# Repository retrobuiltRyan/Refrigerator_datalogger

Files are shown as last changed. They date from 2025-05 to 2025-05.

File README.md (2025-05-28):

What happens to your refrigerator temperature when you open the door? When you leave the door open? I built a data-logging device and stuck it in my fridge for a few hours to find out. I have no idea why I spent a weekend doing this.
Arduino logs temp and humidity data to a microSD card. Use exel to graph and plot data. A photosensor confirms the fridge light if you open the door. Sample graph of data is shown. The old fridge form this experience has a wide temp swing. Not a great fridge, ( came with the rental).

circuit

https://youtu.be/RkxqKmEyWRI

data spoiler

PCB (Arduino Uno shield) too! Note the i2c pwr lables have a text error on the silkscreen. (oops)
PCB

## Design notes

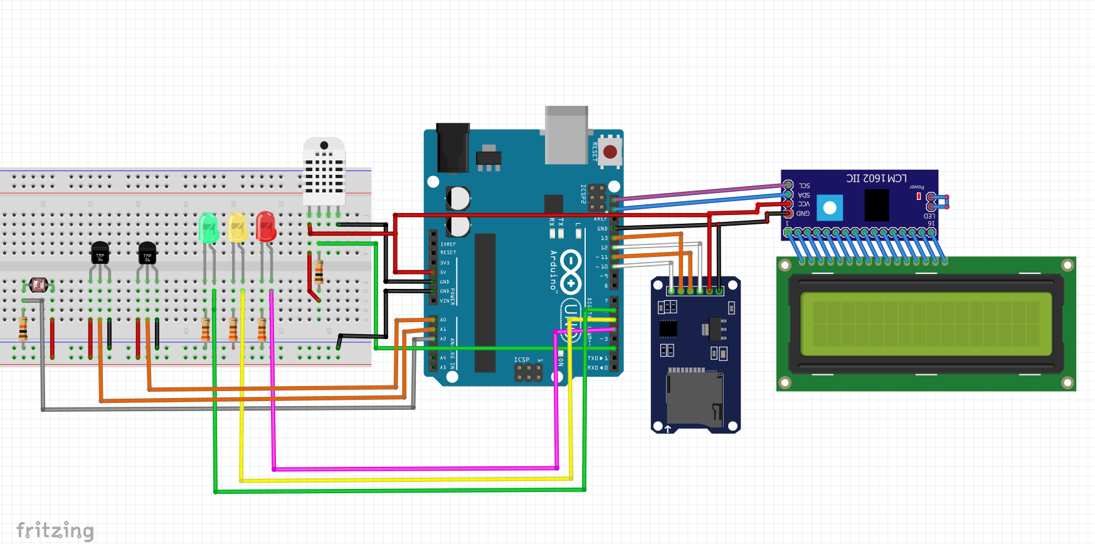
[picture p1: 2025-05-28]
circuit.PNG

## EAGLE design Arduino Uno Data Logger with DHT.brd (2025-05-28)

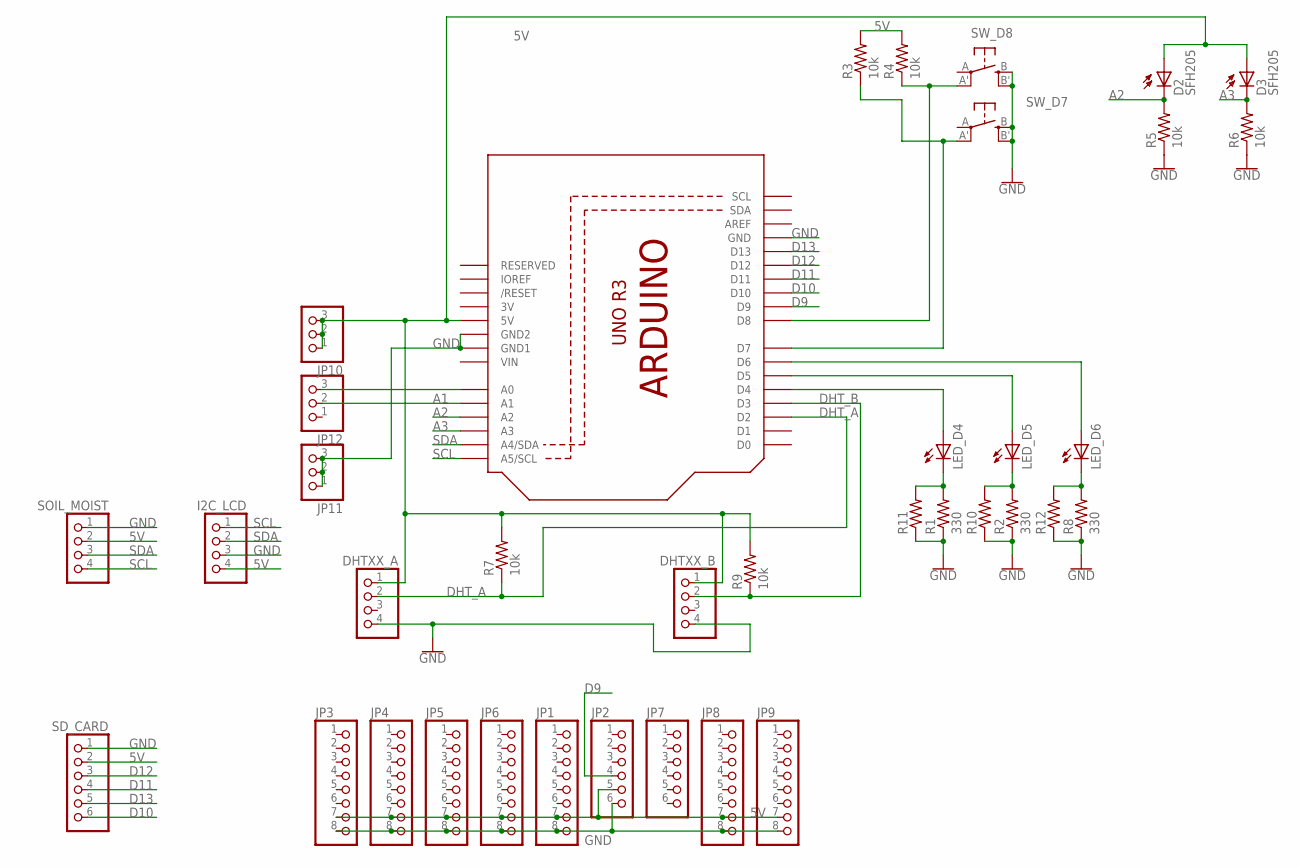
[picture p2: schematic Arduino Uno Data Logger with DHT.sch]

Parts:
D2, D3: SFH205
DHTXX_A: PINHD-1X4; 1X04
DHTXX_B: PINHD-1X4; 1X04
I2C_LCD: PINHD-1X4; 1X04
JP1, JP3, JP4, JP5, JP6, JP8, JP9: PINHD-1X8CLEANBIG; 1X08-CLEANBIG
JP2, JP7: PINHD-1X6CB; 1X06-CLEANBIG
JP10, JP11, JP12: PINHD-1X3CB; 1X03-CLEANBIG
LED_D4, LED_D5, LED_D6: LED5MM
R1, R2, R8: 330; 0207/10
R3, R4, R5, R6, R7, R9: 10k; 0207/10
R10, R11, R12: R-US_R2010; R2010
SD_CARD: PINHD-1X6; 1X06
SOIL_MOIST: PINHD-1X4; 1X04
SW_D7, SW_D8: SPST_TACT-EVQQ2; EVQ-Q2
U1: ARDUINOR3-DIMENSION; ARDUINOR3

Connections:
3V: U1.3V
5V: D2.A, D3.A, DHTXX_A.1, DHTXX_B.1, I2C_LCD.4, JP1.7, JP2.5, JP3.7, JP4.7, JP5.7, JP6.7, JP8.7, JP9.7, JP10.1, JP10.2, JP10.3, R3.2, R4.2, R7.2, R9.2, SD_CARD.2, SOIL_MOIST.2, U1.5V
A1: JP12.2, U1.A1
A2: D2.K (C), R5.2, U1.A2
A3: D3.K (C), R6.2, U1.A3
D9: JP2.4, U1.D9
D10: SD_CARD.6, U1.D10
D11: SD_CARD.4, U1.D11
D12: SD_CARD.3, U1.D12
D13: SD_CARD.5, U1.D13
DHT_A: DHTXX_A.2, R7.1, U1.D2
DHT_B: DHTXX_B.2, R9.1, U1.D3
GND: DHTXX_A.4, DHTXX_B.4, I2C_LCD.3, JP1.8, JP2.6, JP3.8, JP4.8, JP5.8, JP6.8, JP8.8, JP9.8, JP11.1, JP11.2, JP11.3, R1.1, R2.1, R5.1, R6.1, R8.1, R10.1, R11.1, R12.1, SD_CARD.1, SOIL_MOIST.1, SW_D7.B (S), SW_D7.B' (S1), SW_D8.B (S), SW_D8.B' (S1), U1.GND, U1.GND1, U1.GND2
unnamed: R4.1, SW_D8.A' (P1), U1.D8
unnamed: R3.1, SW_D7.A' (P1), U1.D7
unnamed: LED_D5.K (C), R2.2, R10.2
unnamed: LED_D4.A, U1.D4
unnamed: LED_D4.K (C), R1.2, R11.2
unnamed: LED_D5.A, U1.D5
unnamed: LED_D6.A, U1.D6
unnamed: LED_D6.K (C), R8.2, R12.2
unnamed: JP12.3, U1.A0
SCL: I2C_LCD.1, SOIL_MOIST.4, U1.A5 (A5/SCL)
SDA: I2C_LCD.2, SOIL_MOIST.3, U1.A4 (A4/SDA)
VIN: U1.VIN

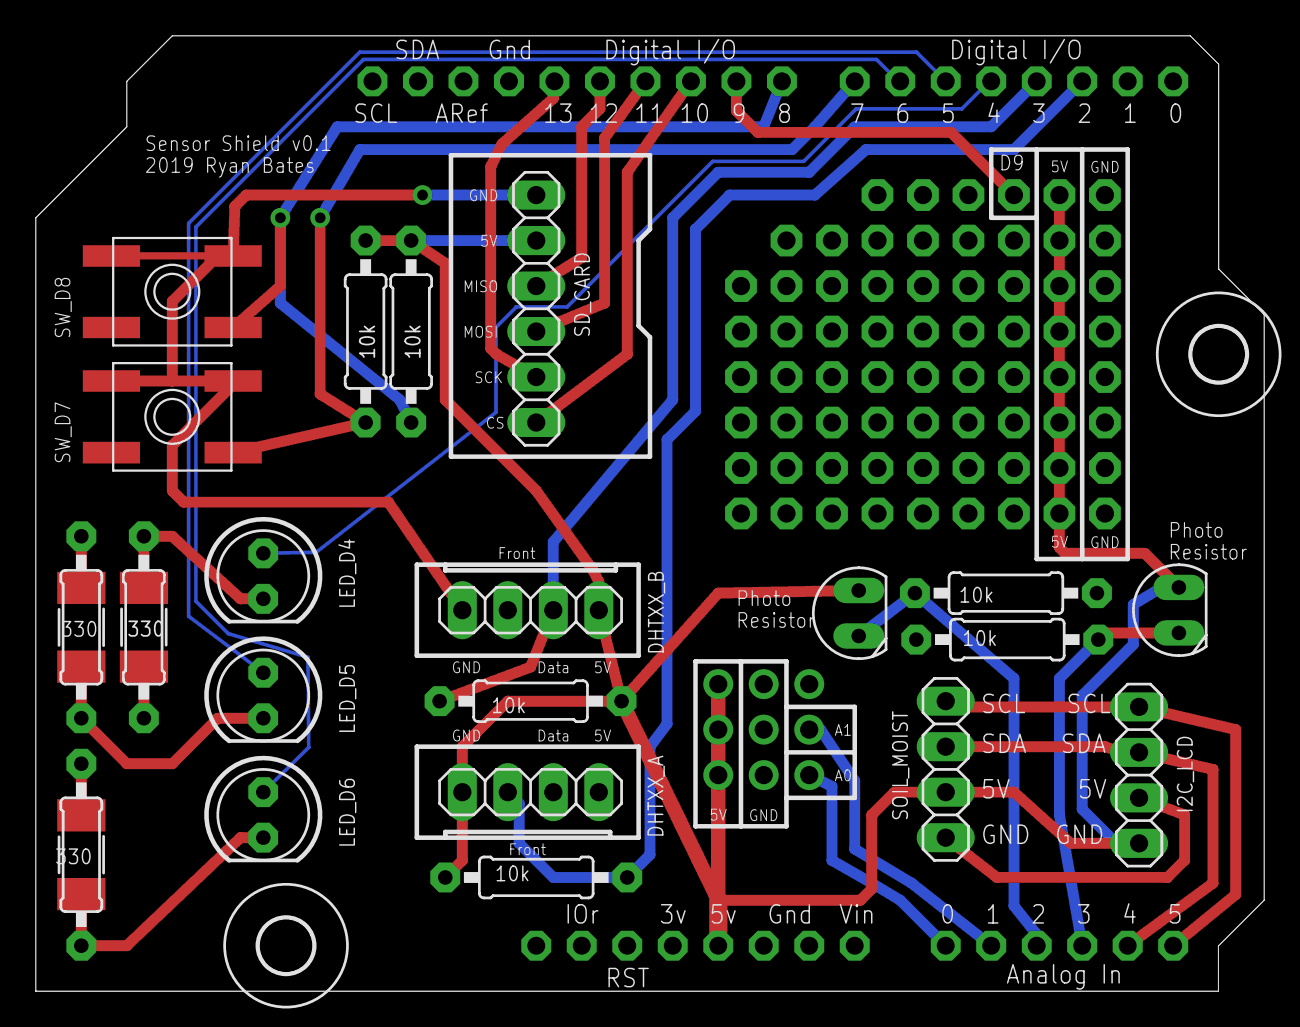
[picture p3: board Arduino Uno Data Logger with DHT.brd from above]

Board: 2 copper layers, 68.6 x 53.3 mm, 39 parts (0 on the bottom side), 23 nets.

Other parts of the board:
U$1, U$3: 3,0

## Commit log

2025-05-28 Arduino code
2025-05-28 eagle design files
    this is an old project, i would say it might contain an error that i forgot about.
    [Arduino Uno Data Logger with DHT.brd, Arduino Uno Data Logger with DHT.sch]

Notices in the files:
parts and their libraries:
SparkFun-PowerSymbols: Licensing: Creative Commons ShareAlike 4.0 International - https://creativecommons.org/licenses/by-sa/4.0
